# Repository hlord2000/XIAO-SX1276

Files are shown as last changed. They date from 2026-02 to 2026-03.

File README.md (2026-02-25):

# Seeeduino XIAO Project Template

<p align="center">
  A mostly unpopulated PCB with a few connectors
</p>

This KiCAD Template simplifies initial setup for Seeeduino XIAO or Adafruit QT Py PCB designs.

To begin, clone this repository to your KICAD_USER_TEMPLATE_DIR as found under "Preferences > Configure Paths..."

Next, use "File > New Project from Template..." or "Ctrl+T" and select "User Templates." Select the template and begin!

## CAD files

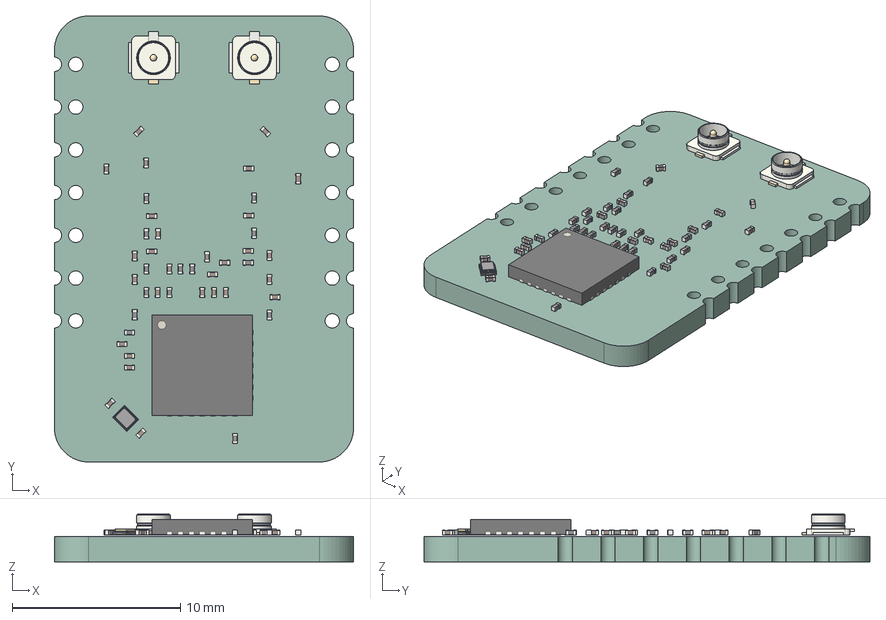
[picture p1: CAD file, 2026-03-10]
build/board.step
17.8 x 26.5 x 2.85 mm
U.FL_Hirose_U.FL-R-SMT-1_Vertical x 2
C_0201_0603Metric x 30
L_0201_0603Metric x 13
Crystal_SMD_1210-4Pin_1.2x1.0mm
QFN-28-1EP_6x6mm_P0.65mm_EP4.8x4.8mm
XIAO-SX1276_PCB

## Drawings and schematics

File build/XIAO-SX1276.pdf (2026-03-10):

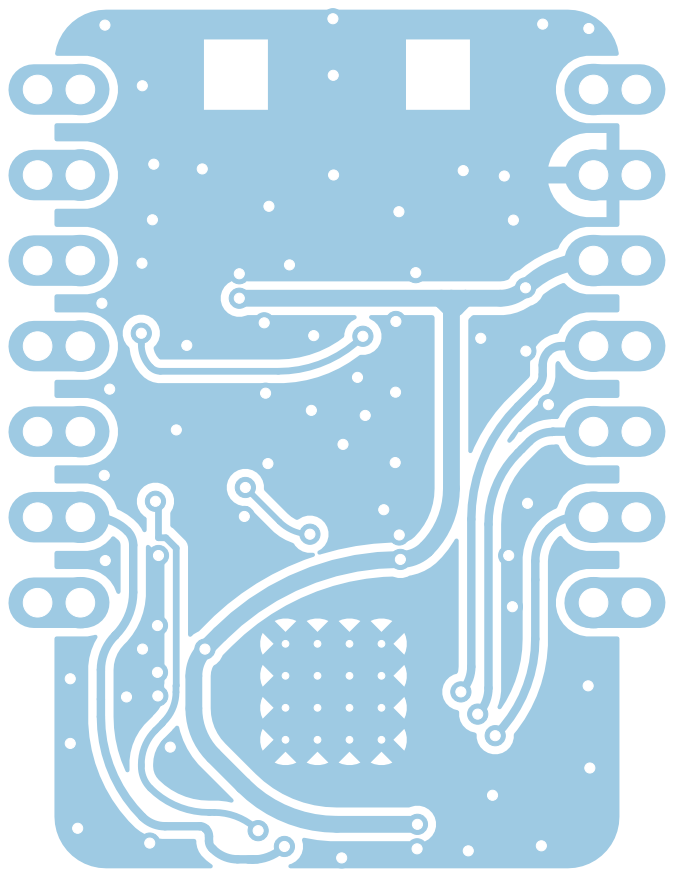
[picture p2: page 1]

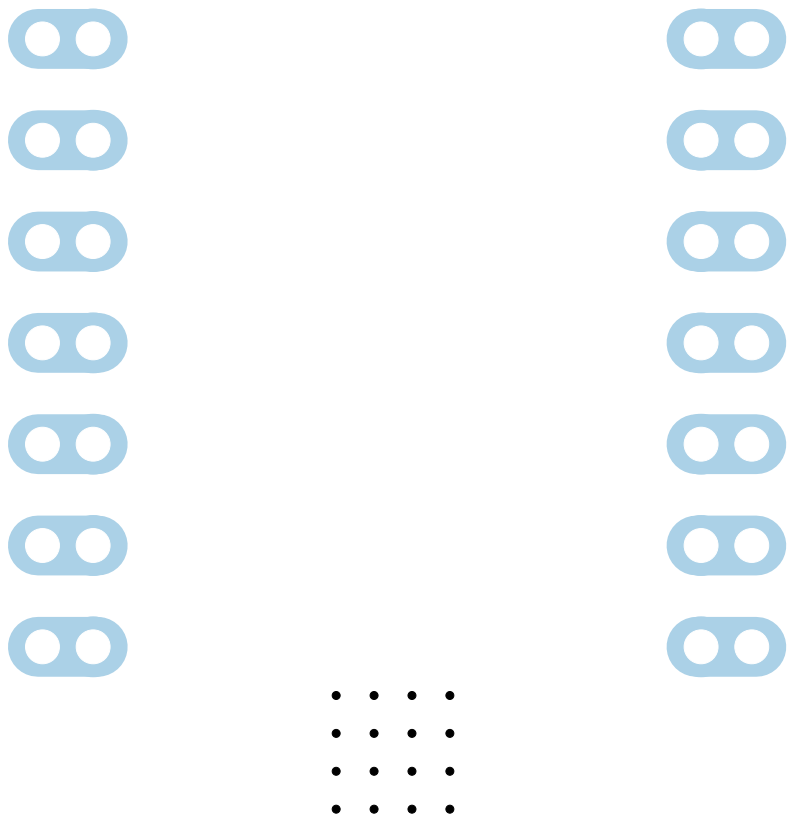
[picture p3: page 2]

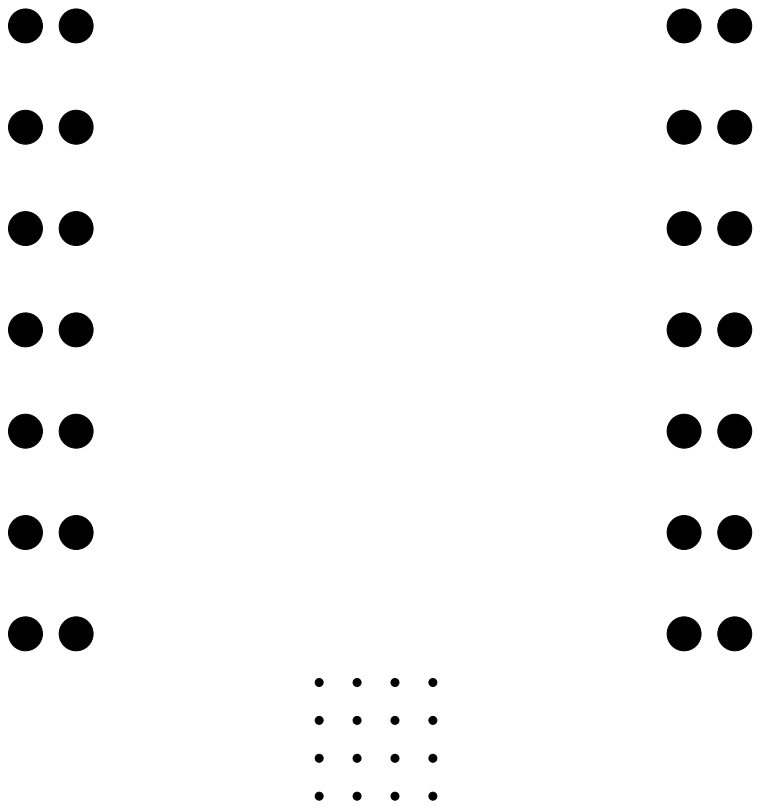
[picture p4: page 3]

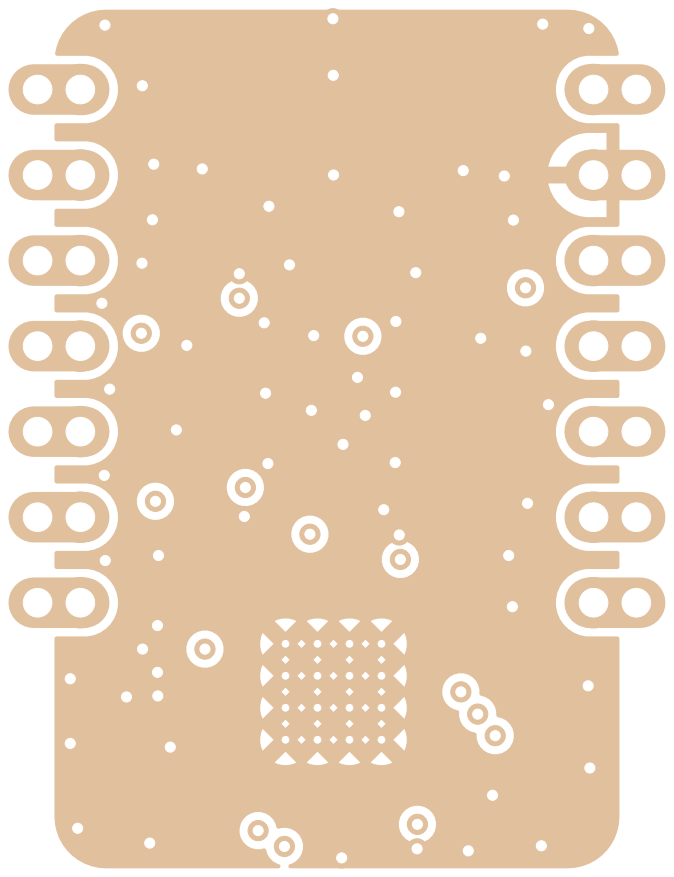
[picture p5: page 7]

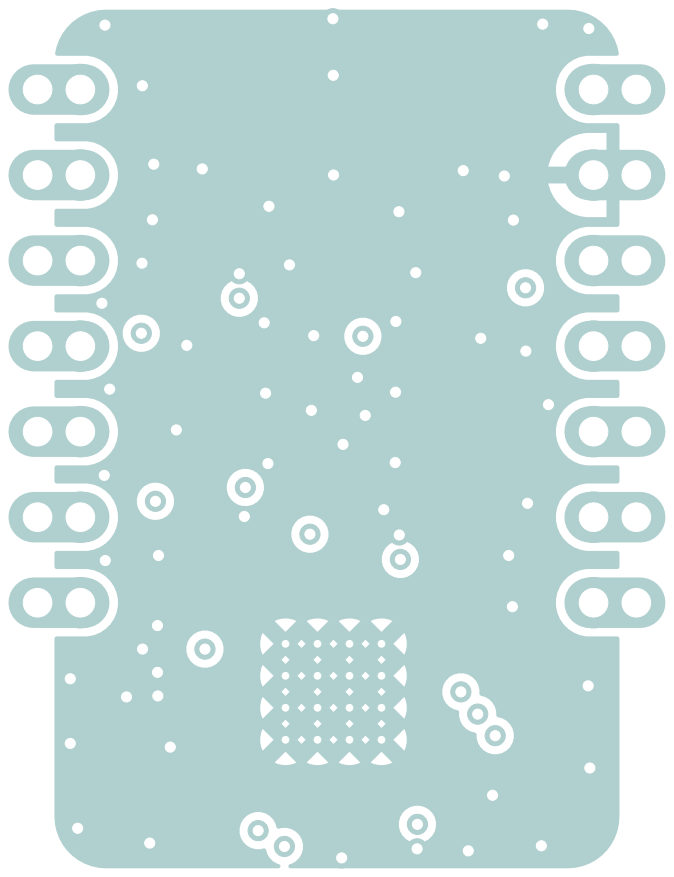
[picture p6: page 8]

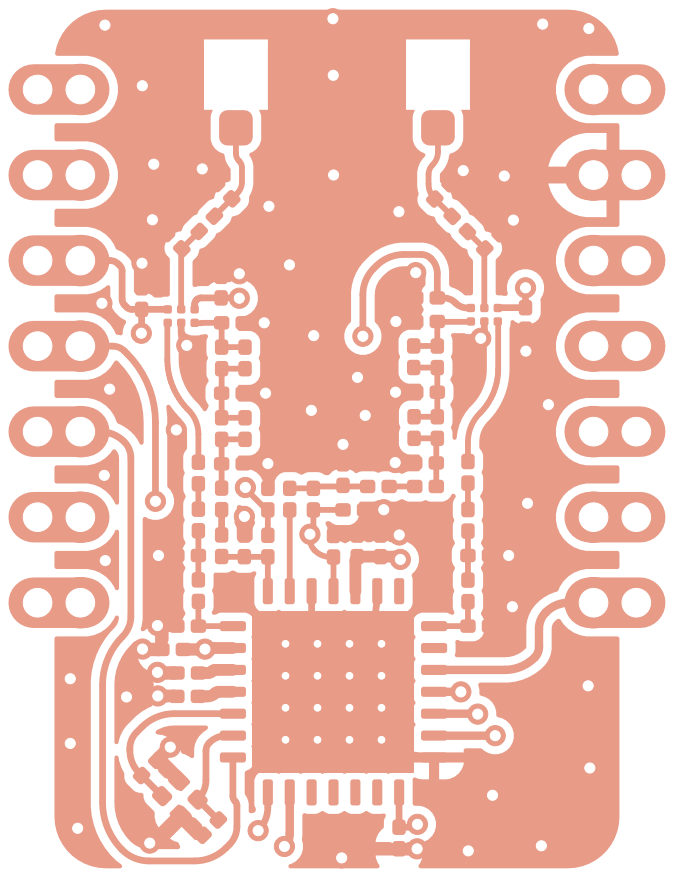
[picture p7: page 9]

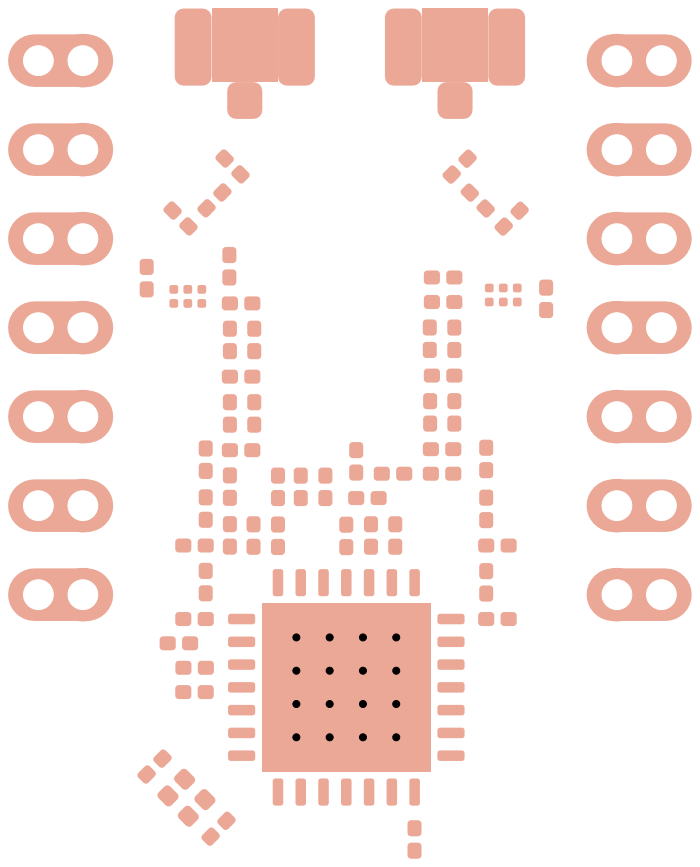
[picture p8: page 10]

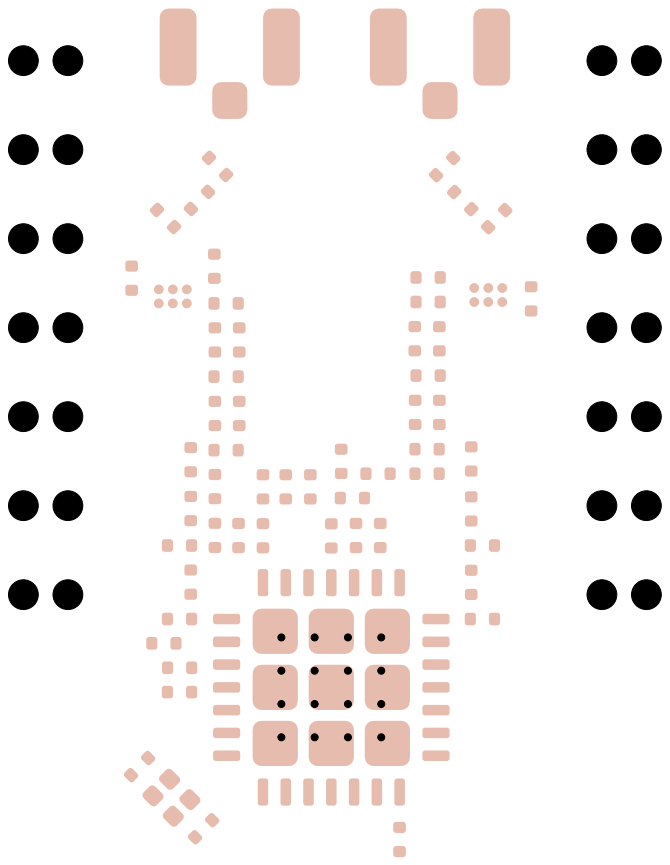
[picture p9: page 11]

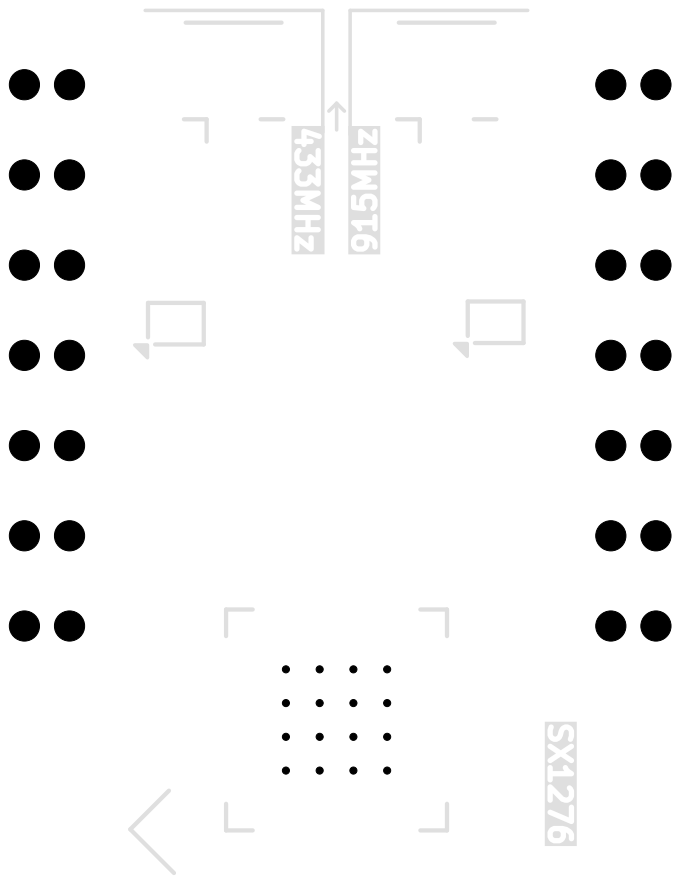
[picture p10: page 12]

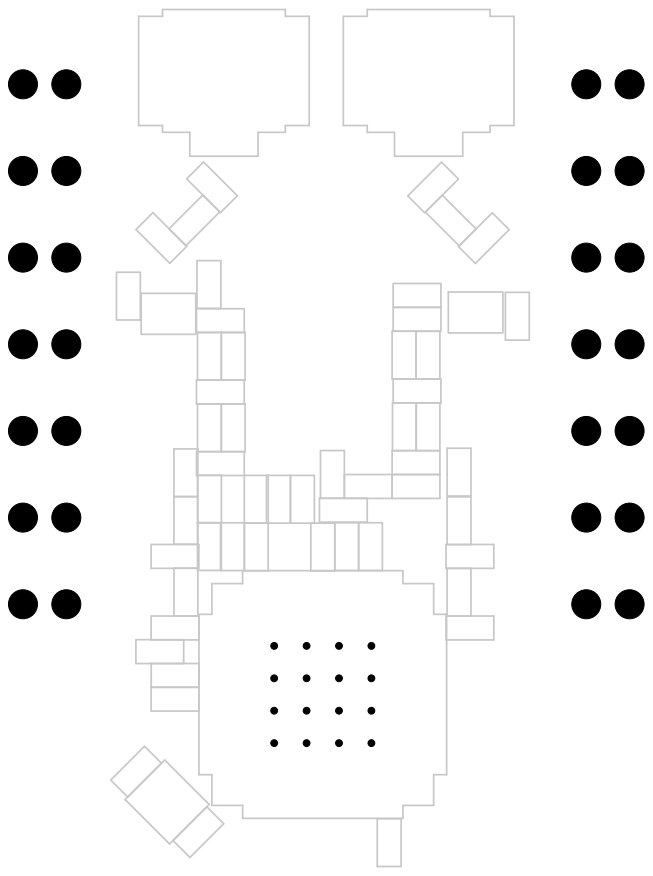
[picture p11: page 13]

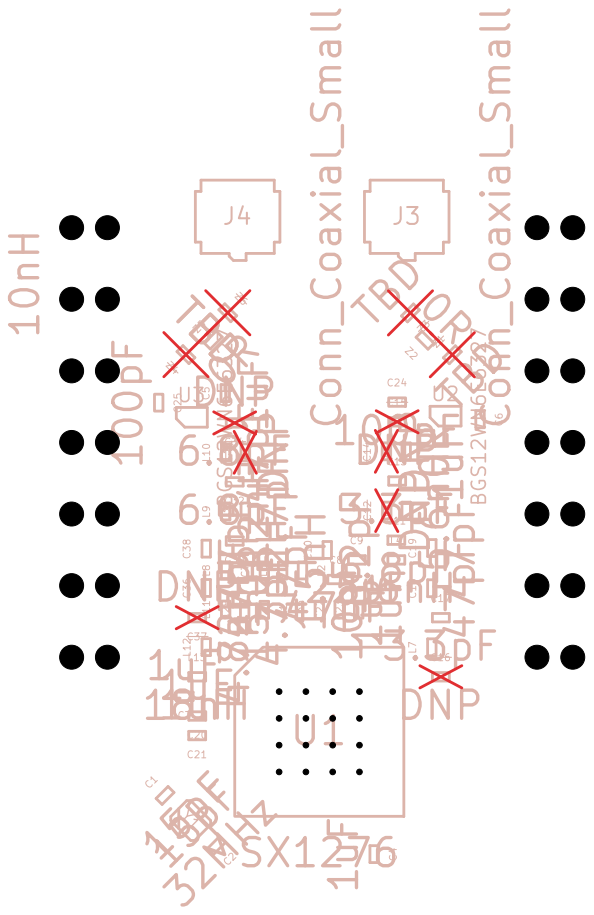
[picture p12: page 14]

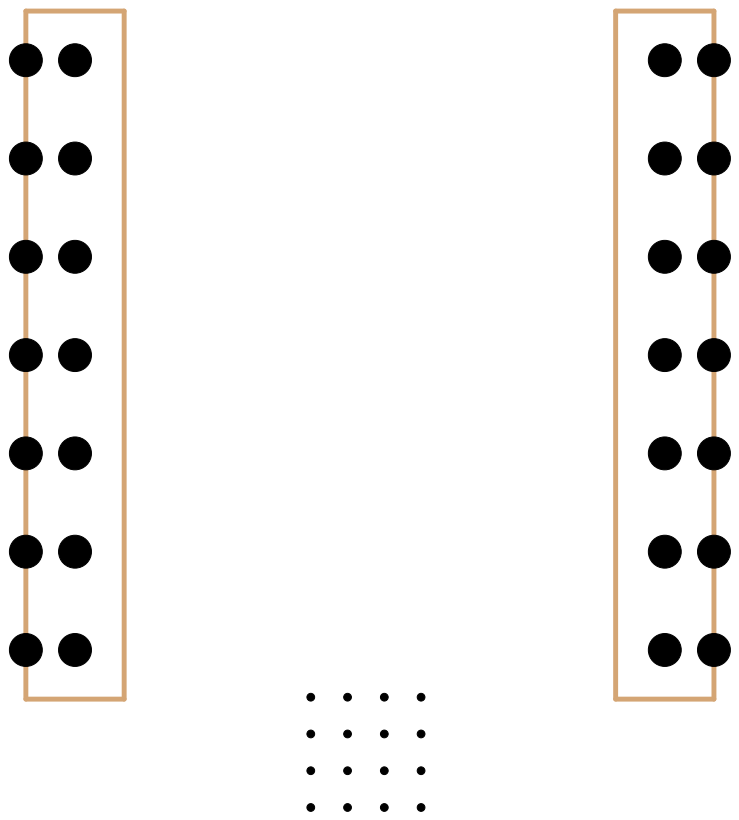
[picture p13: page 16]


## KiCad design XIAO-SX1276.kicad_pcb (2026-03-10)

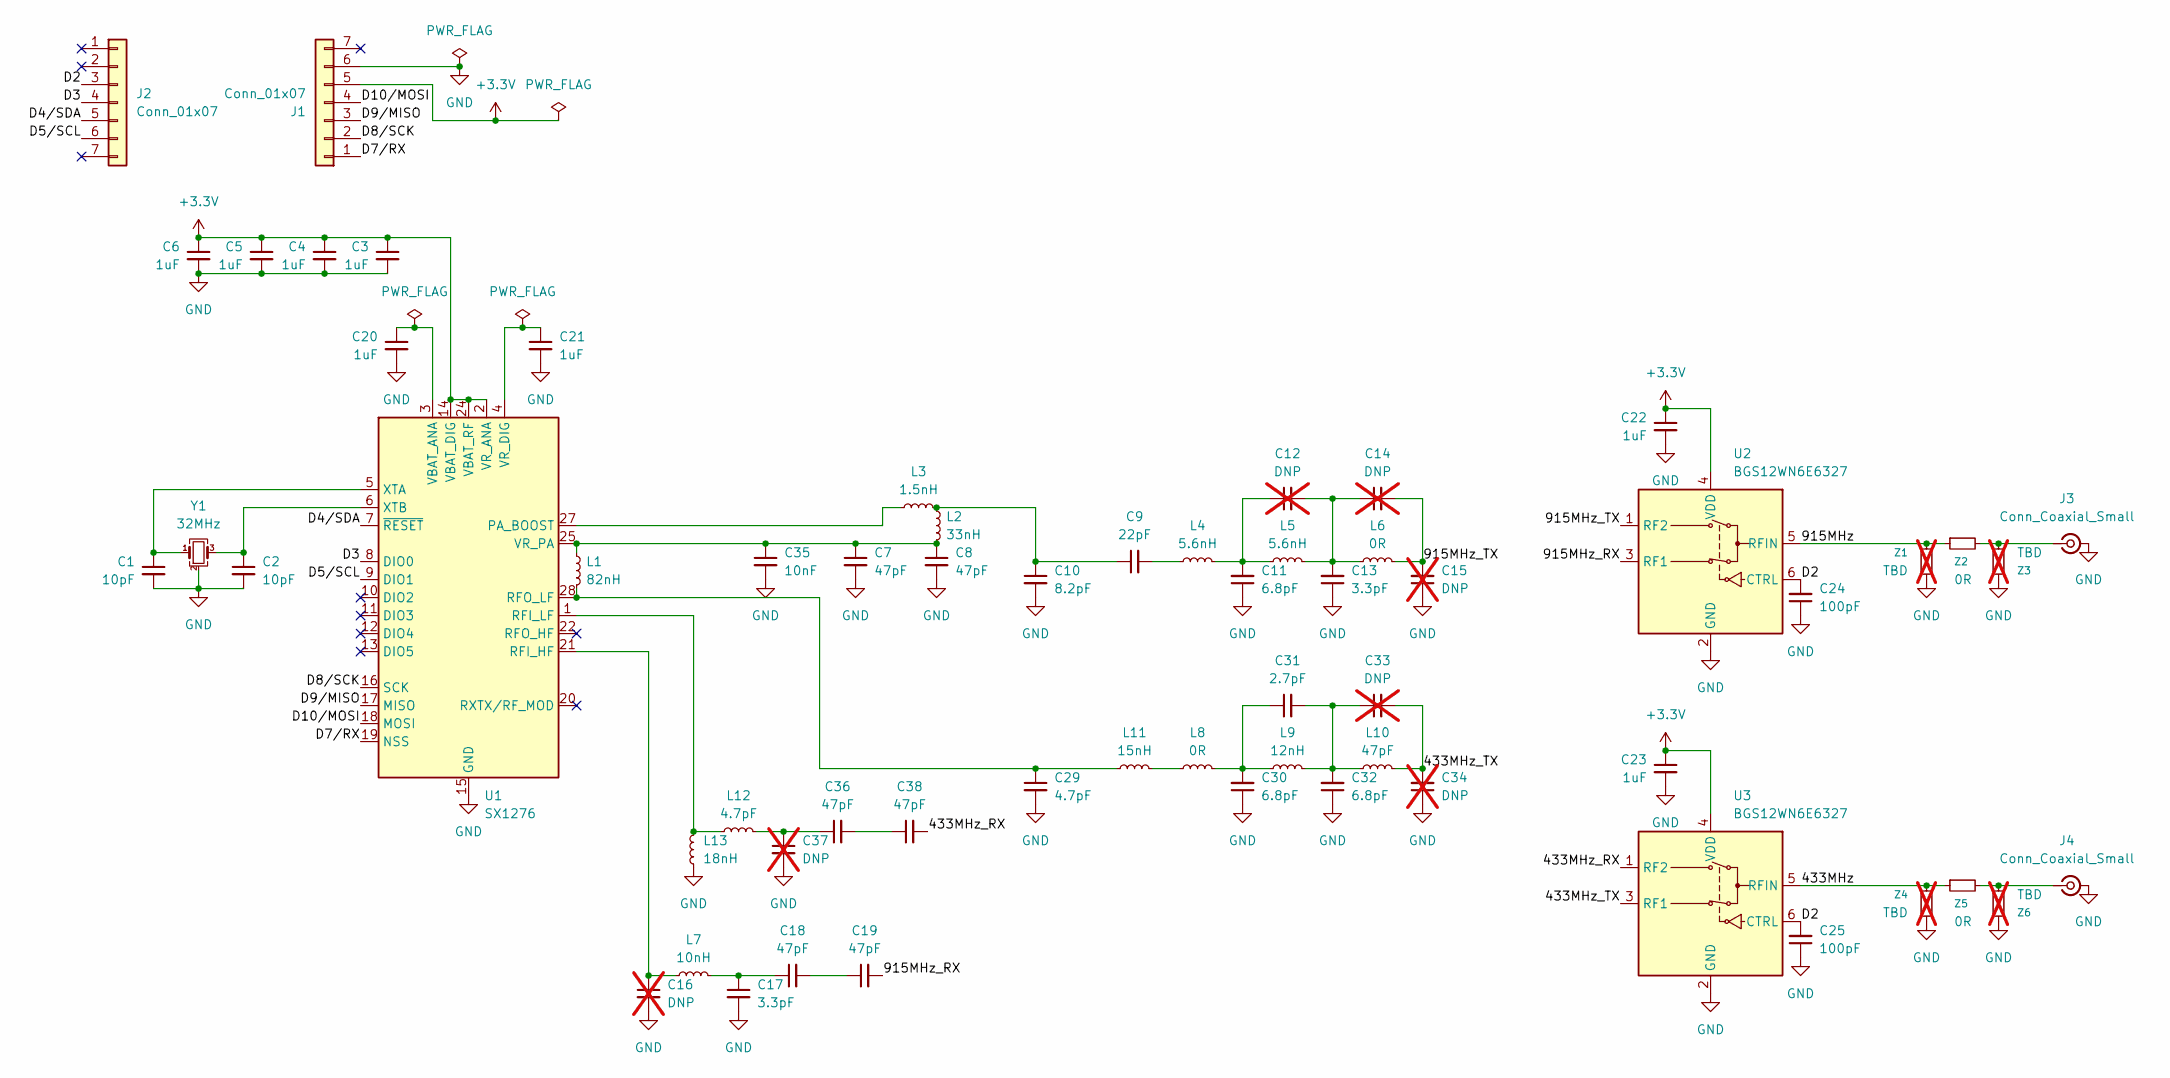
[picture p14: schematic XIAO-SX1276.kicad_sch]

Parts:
C1, C2: 10pF; C_0201_0603Metric; LCSC C76921
C3, C4, C5, C6, C20, C21, C22, C23: 1uF; C_0201_0603Metric; LCSC C76935
C7, C8, C18, C19, C36, C38: 47pF; C_0201_0603Metric; LCSC C85908
C9: 22pF; C_0201_0603Metric; LCSC C76924
C10: 8.2pF; C_0201_0603Metric; LCSC C85918
C11, C30, C32: 6.8pF; C_0201_0603Metric; LCSC C338045
C12, C14, C15, C16, C33, C34, C37: DNP; C_0201_0603Metric; not fitted
C13, C17: 3.3pF; C_0201_0603Metric; LCSC C85906
C24, C25: 100pF; C_0201_0603Metric; LCSC C76922
C29: 4.7pF; C_0201_0603Metric; LCSC C161428
C31: 2.7pF; C_0201_0603Metric; LCSC C85902
C35: 10nF; C_0201_0603Metric; LCSC C85930
J1, J2: Conn_01x07; H7-HALF-HOLE-2.54
J3, J4: Conn_Coaxial_Small; U.FL_Hirose_U.FL-R-SMT-1_Vertical; LCSC C88374
L1: 82nH; L_0201_0603Metric; LCSC C1857896
L2: 33nH; L_0201_0603Metric; LCSC C162611
L3: 1.5nH; L_0201_0603Metric; LCSC C77114
L4, L5: 5.6nH; L_0201_0603Metric; LCSC C237444
L6, L8: 0R; L_0201_0603Metric; LCSC C22458608
L7: 10nH; L_0201_0603Metric; LCSC C162594
L9: 12nH; L_0201_0603Metric; LCSC C162597
L10: 47pF; L_0201_0603Metric; LCSC C85908
L11: 15nH; L_0201_0603Metric; LCSC C98038
L12: 4.7pF; L_0201_0603Metric; LCSC C161428
L13: 18nH; L_0201_0603Metric; LCSC C162600
U1: SX1276; QFN-28-1EP_6x6mm_P0.65mm_EP4.8x4.8mm_ThermalVias; LCSC C80171
U2, U3: BGS12WN6E6327; Infineon_PG-TSNP-6-10_0.7x1.1mm_0.7x1.1mm_P0.4mm; LCSC C1854968
Y1: 32MHz; Crystal_SMD_1210-4Pin_1.2x1.0mm; LCSC C19858538
Z1, Z3, Z4, Z6: TBD; C_0201_0603Metric; not fitted
Z2, Z5: 0R; C_0201_0603Metric; LCSC C22458608

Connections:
+3.3V: C3.1, C4.1, C5.1, C6.1, C22.1, C23.1, J1.5, U1.2 (VR_ANA), U1.14 (VBAT_DIG), U1.24 (VBAT_RF), U2.4 (VDD), U3.4 (VDD)
/433MHz: U3.5 (RFIN), Z4.1, Z5.1
/433MHz_RX: C38.2, U3.1 (RF2)
/433MHz_TX: C33.2, C34.2, L10.2, U3.3 (RF1)
/915MHz: U2.5 (RFIN), Z1.1, Z2.1
/915MHz_RX: C19.2, U2.3 (RF1)
/915MHz_TX: C14.2, C15.2, L6.2, U2.1 (RF2)
/D2: C24.2, C25.2, J2.3, U2.6 (CTRL), U3.6 (CTRL)
/D3: J2.4, U1.8 (DIO0)
/D4/SDA: J2.5, U1.7 (~RESET)
/D5/SCL: J2.6, U1.9 (DIO1)
/D7/RX: J1.1, U1.19 (NSS)
/D8/SCK: J1.2, U1.16 (SCK)
/D9/MISO: J1.3, U1.17 (MISO)
/D10/MOSI: J1.4, U1.18 (MOSI)
GND: C1.2, C2.2, C3.2, C4.2, C5.2, C6.2, C7.2, C8.2, C10.2, C11.1, C13.1, C15.1, C16.2, C17.2, C20.2, C21.2, C22.2, C23.2, C24.1, C25.1, C29.2, C30.1, C32.1, C34.1, C35.2, C37.2, J1.6, J3.2 (Ext), J4.2 (Ext), L13.1, U1.15 (GND), U1.23 (GND), U1.26 (GND), U1.29 (GND), U2.2 (GND), U3.2 (GND), Y1.2 (G), Y1.4 (G), Z1.2, Z3.1, Z4.2, Z6.1
unnamed: C9.2, L4.1
unnamed: C9.1, C10.1, L2.1, L3.2
unnamed: C11.2, C12.1, L4.2, L5.1
unnamed: C12.2, C13.2, C14.1, L5.2, L6.1
unnamed: C17.1, C18.1, L7.2
unnamed: C18.2, C19.1
unnamed: C30.2, C31.1, L8.2, L9.1
unnamed: C31.2, C32.2, C33.1, L9.2, L10.1
unnamed: C36.1, C37.1, L12.2
unnamed: C36.2, C38.1
unnamed: J3.1 (In), Z2.2, Z3.2
unnamed: J4.1 (In), Z5.2, Z6.2
unnamed: L8.1, L11.2
unnamed: L3.1, U1.27 (PA_BOOST)
unnamed: C16.1, L7.1, U1.21 (RFI_HF)
unnamed: L12.1, L13.2, U1.1 (RFI_LF)
unnamed: C29.1, L1.2, L11.1, U1.28 (RFO_LF)
unnamed: C20.1, U1.3 (VBAT_ANA)
unnamed: C21.1, U1.4 (VR_DIG)
unnamed: C7.1, C8.1, C35.1, L1.1, L2.2, U1.25 (VR_PA)
unnamed: C1.1, U1.5 (XTA), Y1.1
unnamed: C2.1, U1.6 (XTB), Y1.3

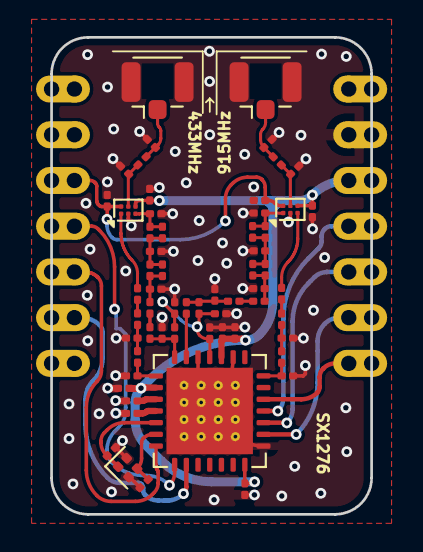
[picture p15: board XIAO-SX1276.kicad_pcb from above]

Board: 4 copper layers, 17.8 x 26.5 mm, 62 parts (0 on the bottom side), 38 nets.

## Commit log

2026-02-25 Initial commit.
    [XIAO-SX1276.kicad_pcb, XIAO-SX1276.kicad_sch]
2026-03-10 Updated BOM
    [XIAO-SX1276.kicad_sch, board.step]
